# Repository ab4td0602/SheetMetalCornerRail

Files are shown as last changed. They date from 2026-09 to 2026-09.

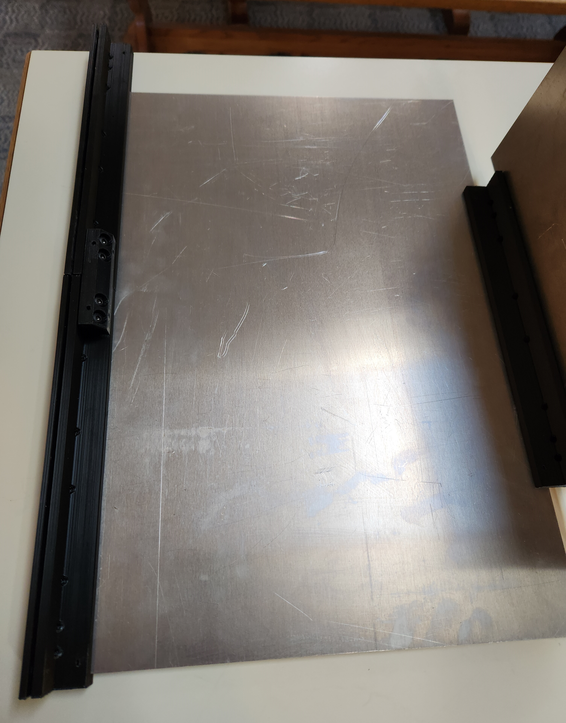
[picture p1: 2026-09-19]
Rail2_temp.png

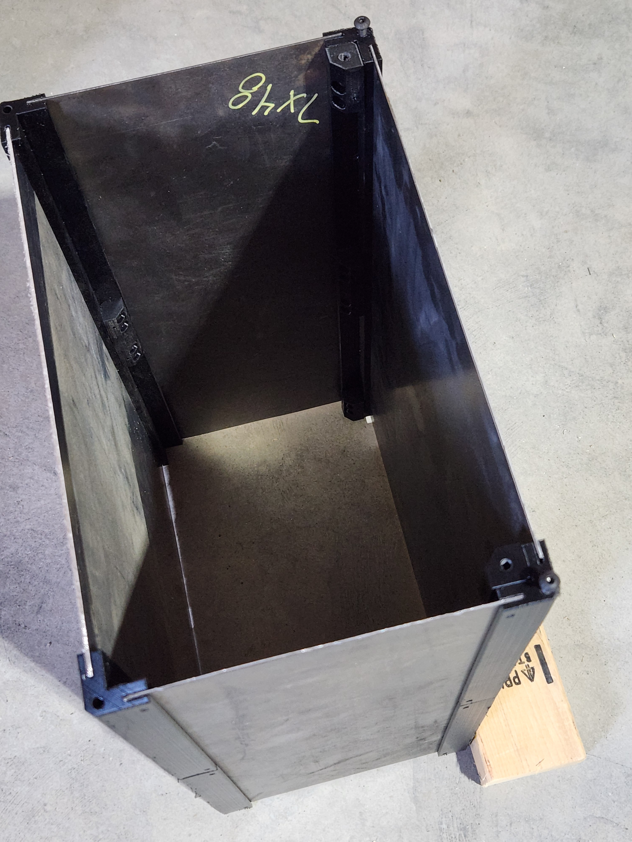
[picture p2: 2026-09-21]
Box1.jpg

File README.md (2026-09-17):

# SheetMetalCornerRail
I have python scripts for FreeCAD that will generate FreeCAD drawings for creating  Corner Rails for sheet material.
These are for making boxes.  You need 4 rails to build a box in order to connect top bottom, and the two sides. These are connected 
via slots in each rail tailored to the type of sheet material used.   The box ends pieces have to be connected 
vi 4  5mm screw holes located at the ends of each of the 4 rails.   Not very complicated.  I will provide some pictures as
I complete some boxes. I need to build a 480 x 110 x 304.8 box to install a 4 axis Gecko 340 servo drive CNC system with a 
MESA 7i96S controller and using a 60V servo drive power supply. And that is how this project started.  How do you 
build an sturdy, custom box using a variety of different materials. I have a 12ga alumimun sheet 304.8mm x 609.6mm  and a 
16ga steel sheet of the same size on hand. So it was sort it out, and make it work.  I did have a lot of help using Gemini
AI to help create a lot of the python scripts. More so at the beginning, since I had never used python for FreeCAD prior to
this effort.  Much more comfortable about how the syntax works, but not an expert yet.   

The rail has two wings which are at right angles.  The wings are 11mm wide. The wings are 28mm from the top of the wing to the 
corner with a slot depth of 10 mm.  Or if you select 16mm slot depth the wings are 34mm from the top of the wing to the corner.

The part can be used for extruding metal or plastic, but was designed primarily for 3d printing PETG or PETG-CF corner rails.  
The rails have an upper and lower rail slot width size which can be selected separately depending on the type of material being 
used.   This runs from 18ga aluminum, 16ga aluminum, 14ga, aluminum, 12ga aluminum, 16ga steel, 14ga steel, 12ga steel,  1.5 mm, 
2.0mm,  .090 FRP,  and 1/8".   

The first selection to be made is the rail length -  The selection runs from 500mm to 110mm.  Default is 250.00  
The second selection is the type of material to use for the lower wing of the corner rail.  This determines the slot size.
The third selection is the type of material to use for the upper wing of the corner rail.  This allows for a separate choice for slot size.
  The fourth selectin is the slot depth.  To provide for more strength,  there are two sizes of rail.  When a general purpose part is needed  
a 10mm slot depth is provided by default - and the rail being rendered in FreeCAD has 28mm wings.   If you select a 16mm depth slot
the wings will be 34mm.   This takes a lot longer to 3d print. 

The fifth selection is a WARP factor setting and it is the correction you need for being able to print the part at 45 degrees.  I have a
flat on one corner of the part.  This was created to provide a way to have the part face down on that corner, and eliminate any issues 
where supports are needed inside of the slots and holes of the rail.  By placing the part where the vertical sides are now 45 degrees 
instead of 90,  this eliminates any 3d part slicing support issues.  It does create an interesting effect on the actual part creation 
on the 3d printer.  Warping.  My printer setup will print the PETG/PETG-CF parts at about 91.4 included angle printing this way. 
So on my fifth selection I include a WARP angle correction of 1.40.  That correction in the part rendering, will 3d print a 90 included
angle for my setup and PETG.   If you are not using 3d printing -  the default is 0.00.   

-----------------
There are holes in the slots - at 5mm from the bottom of the slots to put 3mm retaining screws,  These are 12mm from each end of the corner
rail and 5mm from the bottom of the slot.  In each sheet being used -  there should be a 3.2mm clearance hole - placed 12mm from the end
and 5mm from the sheet.   The 3mm screw is a pan head and can be tightened to help squeeze the printed plastic slot.  

There are 4.7mm un tapped 5mm holes in either end of the rails at x=0, y=6, and z=6,  and x=(rail length) y=6, and z=6.  These holes are 
15mm deep, and are arranged to secure  end plates/sheets  to 4 rails -  to finish the box enclosure.  To make this work,  the end plates should 
be 38mm greater than the bottom plate is wide and 38mm greater than the side plate is tall.   I would recommend measuring and cutting to 
size after the top, bottom, and sides of the box has been formed.   You do not have to tap the 3d printed holes, as it can be formed
by the 5mm screw, and holds securely, just use a 5M x 16 or 5M x 12 screw.

There are some additional holes in the rail oriented at 45 degrees.   These are provided to accept a coupler which fits between the 
rails. This coupler has matching holes to the rail. These pull into the V of the Rail - and are designed to align two rails coupled to 
extend the overal length. Since the screws pull into the V, these keep the alignment close enough each slot aligns across the two rails. 
And sheet material can extend between the rails.   For instance,  I have two rails at 240mm  and need to have a box that is 480mm. I place
a sheet of material to align the rails and screw in 4 5M x 16 screws through the couplers into the rail.  Now the rails have 4.7mm holes
in the correct spots to match the couplers - and the 5M threads are formed by the screws,   There is a separate function in the coupler 
which is to hold an intermediate sheet for a mezannine to mount electroncs  and it can span above the bottom of the box, by about 9mm.  
There are mounting screws holes for 3mm  on top of the coupler.    Now for each rail the holes in the 45 degree orientation - these are
placed at 17.5, 30, 52.5 from either end of the rail. Additional holes in the middle of the rail are at +17.5 and -17.5 from the middle
of each rail.  That allows for coupling on either end of the rails.   And an additional mid rail tie down for a mezannine sheet. 

Now I only have a single 28mm coupler at the moment.  It will work as a coupler for all rails but it isn't setup for a mezzanine sheet for
16mm slot depth/34mm size parts.  

You can email me at jtsmith0050@gmail.com - if you need assistance.   
file names  -  
PETG_RAIL_7a.py 
CornerRail_Coupler_28m_7b.py

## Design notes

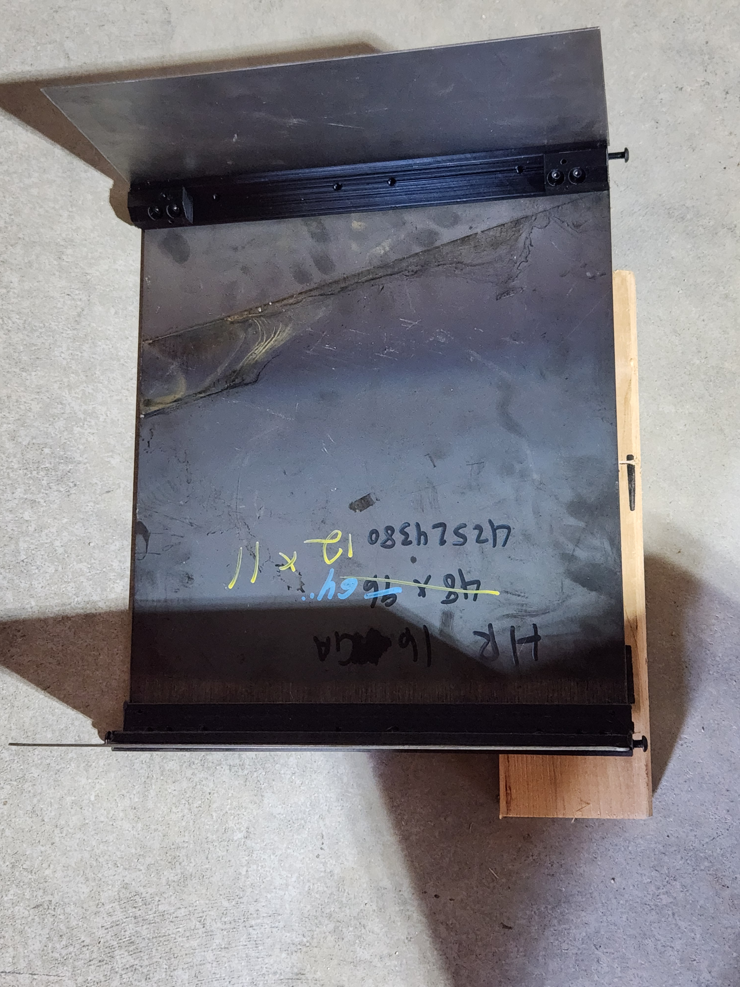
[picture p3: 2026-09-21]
Box2.jpg

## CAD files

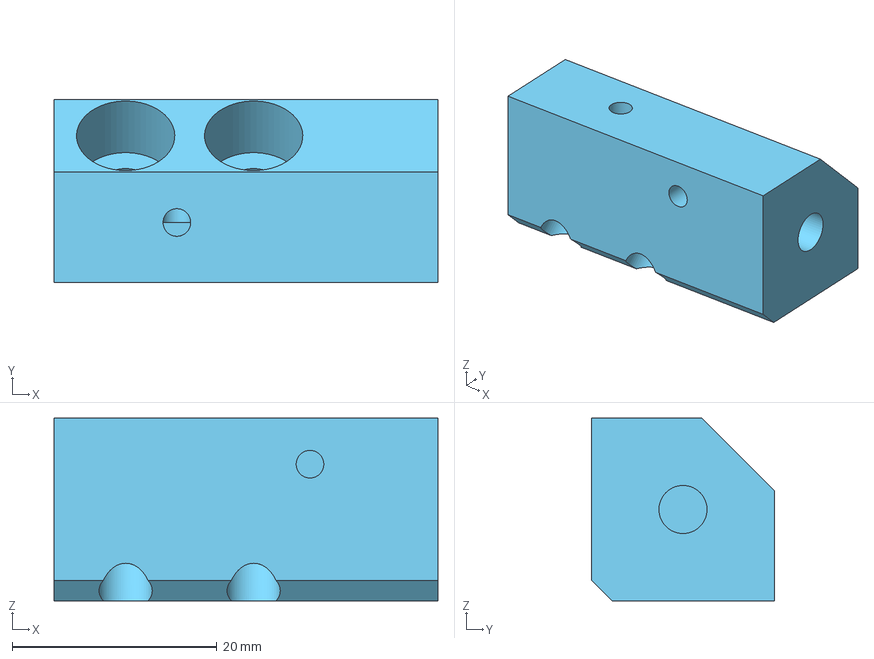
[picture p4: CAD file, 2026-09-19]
EndStop_28mm_7.step
37.5 x 17.9 x 17.9 mm

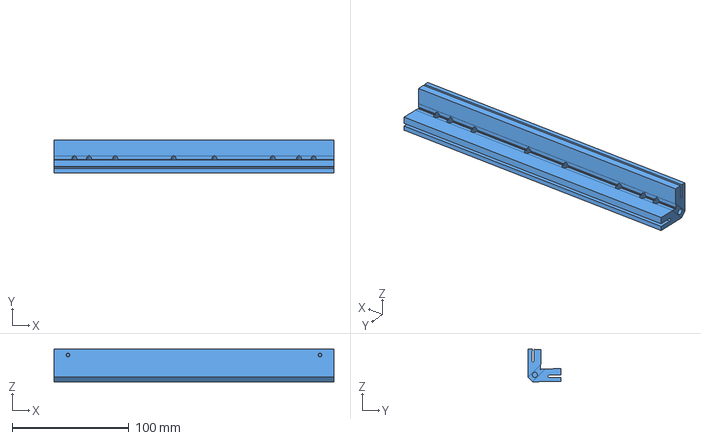
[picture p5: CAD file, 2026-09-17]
PETG_Corner_Rail_P1.4_10m_240m_12gaal_16agst.step
240.0 x 28.5 x 28.0 mm

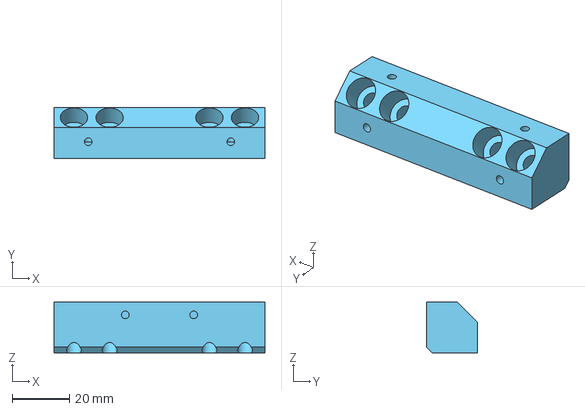
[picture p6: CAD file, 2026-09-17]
Coupler_74mm_28_7b.step
74.0 x 17.9 x 17.9 mm

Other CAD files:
EndStop_28mm_7.stl

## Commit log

2026-09-16 Enhance README with detailed rail specifications
    Expanded README with detailed descriptions of rail features, selections, and assembly instructions.
2026-09-16 Add files via upload
    This is an FreeCAD python file to render custom box rails that will hold sheet metal and other panels in slots arranged at 90 degree angles.
    Four of the Rails are needed to form a box. There are additional holes in each rail end to mount end panels/sheets.
2026-09-16 Add files via upload
    This is a coupler file - designed to connect multiple rails in line- to extend the length.
2026-09-17 Add files via upload
    Coupler - 74mm x 28 - stp file
    [Coupler_74mm_28_7b.step]
2026-09-17 Add files via upload
    Corner Rail - 28mm wings - lower wing 12ga aluminum sheet, upper wing 16ga steel sheet. WARP anglular correction is 1.4 degrees. Slot depth 10mm
    [PETG_Corner_Rail_P1.4_10m_240m_12gaal_16agst.step]
2026-09-17 Enhance README with project details and specifications
    Expanded project description and provided details about the box dimensions and materials used.
2026-09-19 Add files via upload
    Example - 16ga steel sheet inside the lowers slots - 16ga steel sheet on upper rail. The long rail is two rails coupled with the Coupler - 28mm - This the rail length is 240mm and the coupler adds th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
2026-09-19 Add files via upload
    I added an end stop part that fits inside the rail upper and lower wings. It has a 45 degree through hole that fits into the rail at the two outer 45 degree 5mm holes. It will cinch down. At the end 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
    [EndStop_28mm_7.step, EndStop_28mm_7.stl]
2026-09-19 Add files via upload
    The End Stop 35mm part that serves as a way to screw down parts of the box. This part will fit inside the rail "wings" and screw down in the rail 45 degree holes. 5mm x 16 screws. The end sheet/panel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
2026-09-20 Add files via upload
    5 each 240mm corner rails connected via 4 each 28mm connectors - overall length is 1200 mm - Upper slots are for 16ga steel, Lower slots are for 16ga steel. 10mm slot depth. Showing example of how ra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
2026-09-21 Add files via upload
    This is a 480mm - 18.89" long box - 120mm - 7" tall - and 304.8 - 12" wide. I do no have a face plate for this yet- I will make the end plates will be 518mm (20"3/8) - x 342.8 mm (13 1/2 ") wide. The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
2026-09-21 Add files via upload
    This is a project with 300mm rails. 16 guage cold rolled. Tools - scribe, speed square, Harbor Freight Bauer corded shear. I will find some more cold rolled to finish the top of the box and the end p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
